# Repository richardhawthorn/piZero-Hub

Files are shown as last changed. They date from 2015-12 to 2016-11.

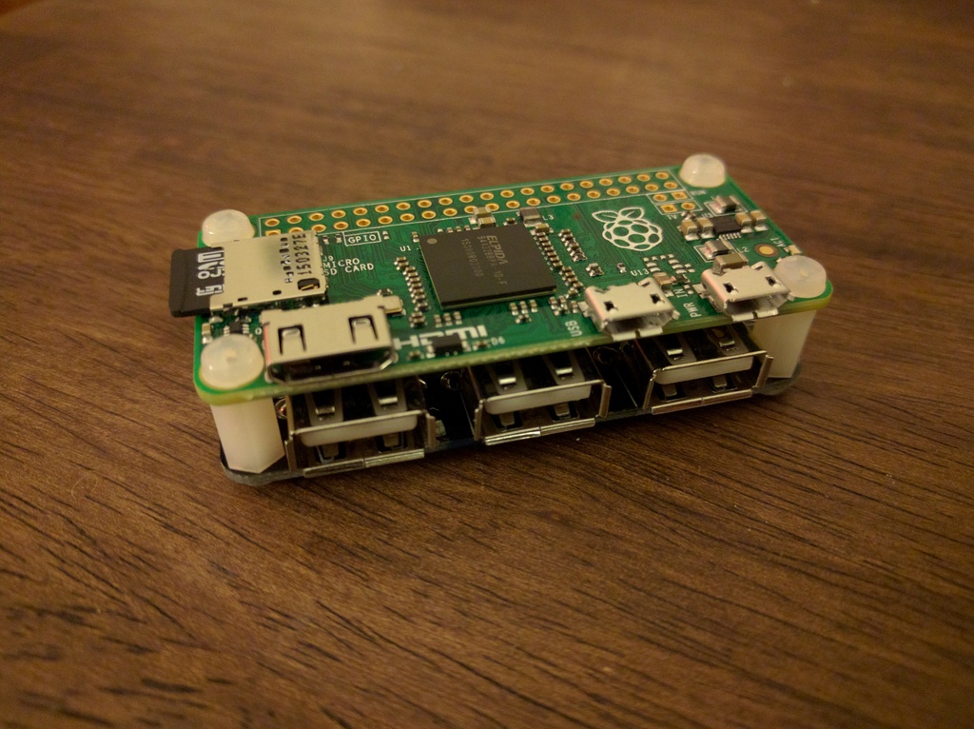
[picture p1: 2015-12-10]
images/image2.jpg

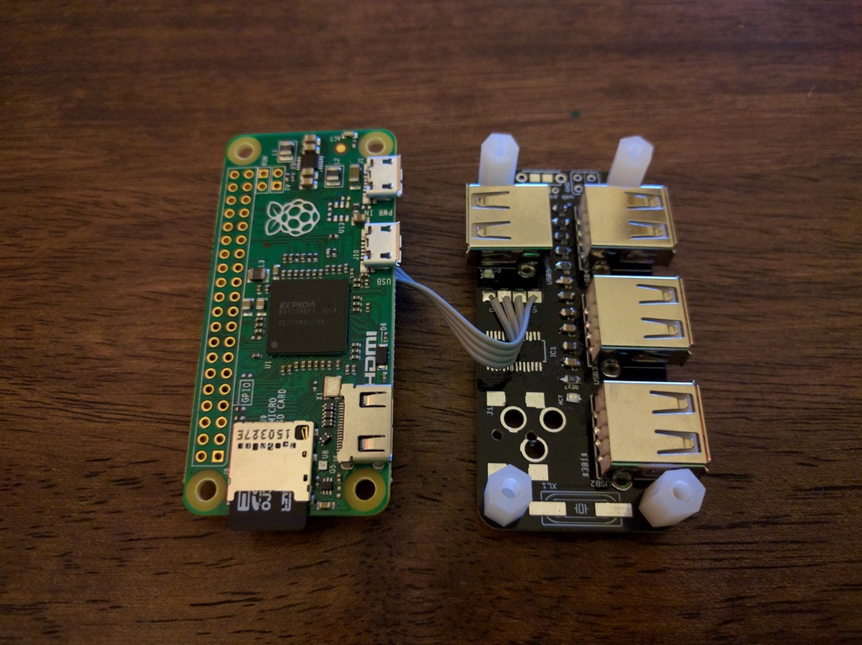
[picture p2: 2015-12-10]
images/image5.jpg

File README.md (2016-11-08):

### Description

USB hub for the Raspberry Pi Zero

### Features

- 4 x USB 2.0 ports
- Micro USB upstream connector
- FE1.1s USB hub chip
- Solder pins for direct connection to the Raspberry Pi Zero
- Power jack connector for external 5v power source
- Optional jumpers to take power from upstream connector
- LED status indicators for each downstream port

### Modes of use

#### 1. Direct solder

You can solder 4 wires directly between the Zero and the hub using 4 pads exposed on both the hub and the Zero. This will connect the 5V, GND, USB D+ and USB D-.

You can then either power the board either using the USB power connector on the Zero, or using the power jack on the hub.

This is the neatest option, although does involve soldering.

#### 2. USB connection

Using a USB OTG cable, or a micro USB to micro USB you can connect the data USB port on the Zero to the upstream USB connector on the side of the hub. Adding the 2 power jumpers allows the hub to use power supplied to the Zero though the power USB connector.

Alternatively, remove the power jumpers and power the hub through the external power jack.

Although a USB cable is needed to connect the two in this mode, no soldering is required.

#### 3. Standalone hub

This board can be used as a regular USB hub, either using power from the upstream USB connector, or through the power jack and external power supply.

### Licence

This work is licensed under the Creative Commons Attribution-ShareAlike 4.0 International License. 
To view a copy of this license, visit http://creativecommons.org/licenses/by-sa/4.0/

Designed by <a xmlns:cc="http://creativecommons.org/ns#" href="http://www.richardhawthorn.com" property="cc:attributionName" rel="cc:attributionURL" target="_blank">Richard Hawthorn</a><br />

Based on design by @MakerBro, https://acrobotic.com

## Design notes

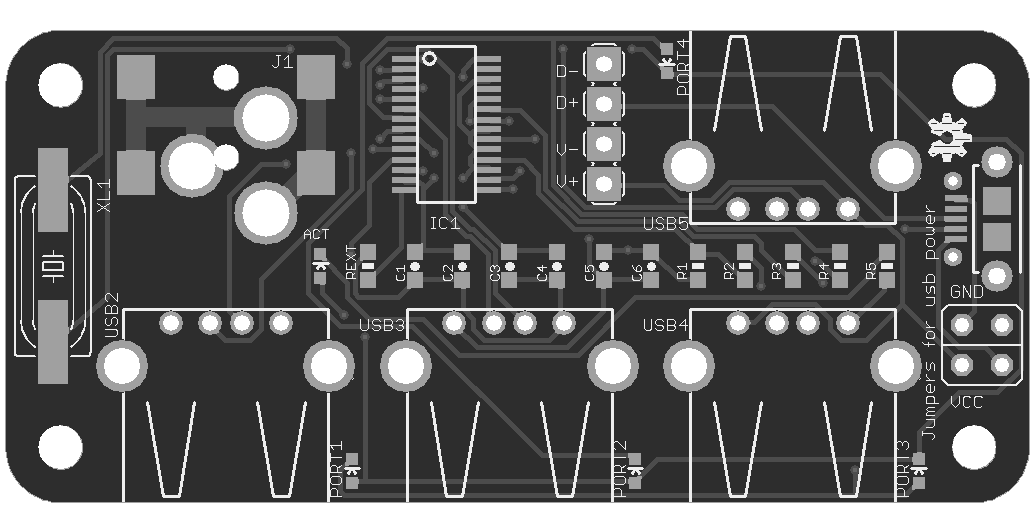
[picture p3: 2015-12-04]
images/pcb_front.png

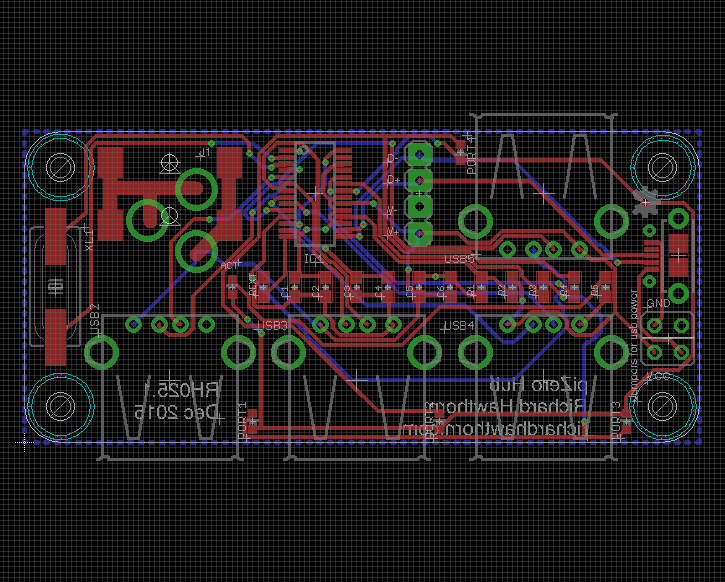
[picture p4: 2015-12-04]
images/eagle.png

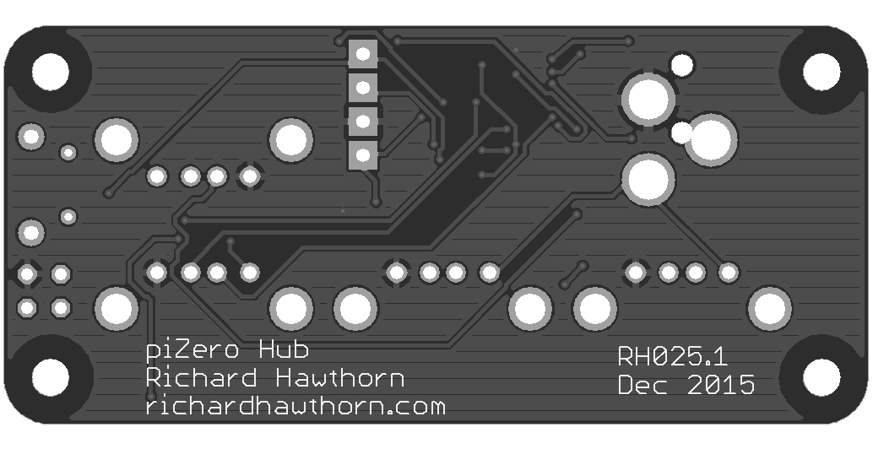
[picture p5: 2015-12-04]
images/pcb_back.png

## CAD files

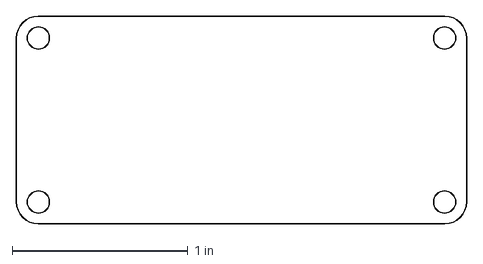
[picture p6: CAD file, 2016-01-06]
enclosure/pizero.dxf
2.56 x 1.18 in

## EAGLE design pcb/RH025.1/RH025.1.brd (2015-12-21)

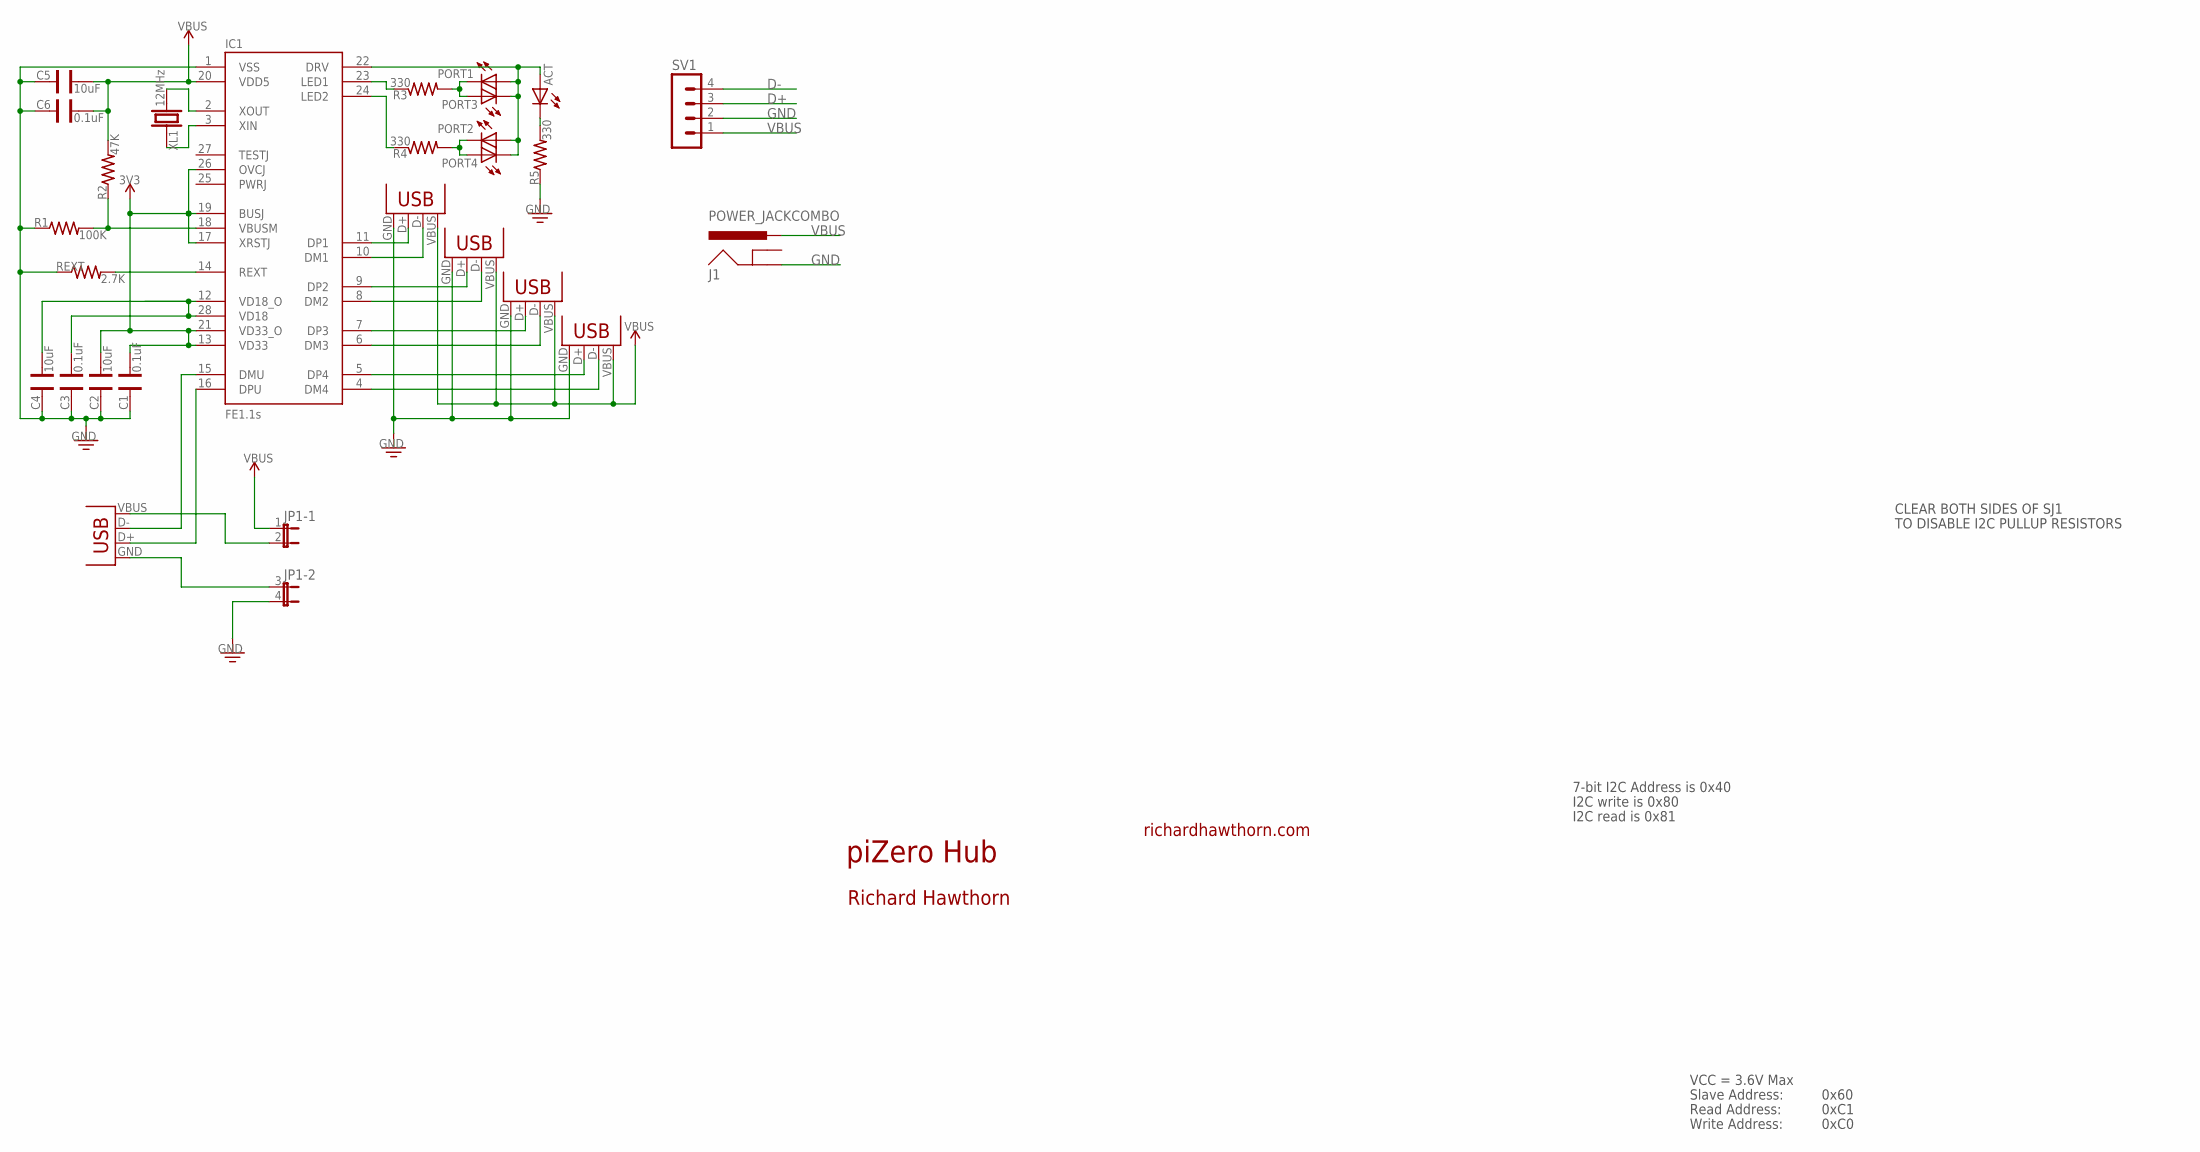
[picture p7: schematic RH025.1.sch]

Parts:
ACT: LED0603; LED-0603
C1, C3, C6: 0.1uF; CAP-0603
C2, C4, C5: 10uF; CAP-0603
IC1: FE1.1S; FE1.1S_SSOP-28
J1: POWER_JACKCOMBO; POWER_JACK_COMBO
JP1: JP2QE; JP2Q
PORT1, PORT2, PORT3, PORT4: LED0603; LED-0603
R1: 100K; RES-0603
R2: 47K; RES-0603
R3, R4, R5: 330; RES-0603
REXT: 2.7K; RES-0603
SV1: MA04-1
USB1: USBMICROB-PTH; USB-MICROB-TH
USB2, USB3, USB4, USB5: USBA-PTH; USB-A-F-PTH
XL1: 12MHz; HC49UP

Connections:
3V3: C1.1, C2.1, IC1.13 (VD33), IC1.17 (XRSTJ), IC1.19 (BUSJ), IC1.21 (VD33_O), IC1.26 (OVCJ)
D+: IC1.16 (DPU), SV1.3, USB1.D+
D-: IC1.15 (DMU), SV1.4, USB1.D-
GND: C1.2, C2.2, C3.2, C4.2, C5.2, C6.2, IC1.1 (VSS), J1.GND@1 (GND), JP1.4 (2), R1.1, R5.1, REXT.1, SV1.2, USB2.GND, USB3.GND, USB4.GND, USB5.GND
unnamed: IC1.14 (REXT), REXT.2
unnamed: JP1.2, USB1.VBUS
unnamed: JP1.3 (1), USB1.GND
unnamed: PORT2.C, PORT4.A, R4.2
unnamed: IC1.2 (XOUT), XL1.2
unnamed: C3.1, C4.1, IC1.12 (VD18_O), IC1.28 (VD18)
unnamed: IC1.3 (XIN), XL1.1
unnamed: IC1.11 (DP1), USB5.D+
unnamed: IC1.10 (DM1), USB5.D-
unnamed: IC1.18 (VBUSM), R1.2, R2.1
unnamed: IC1.9 (DP2), USB4.D+
unnamed: IC1.8 (DM2), USB4.D-
unnamed: IC1.7 (DP3), USB3.D+
unnamed: IC1.6 (DM3), USB3.D-
unnamed: IC1.5 (DP4), USB2.D+
unnamed: IC1.4 (DM4), USB2.D-
unnamed: PORT1.C, PORT3.A, R3.2
unnamed: ACT.C, R5.2
unnamed: IC1.23 (LED1), R3.1
unnamed: IC1.24 (LED2), R4.1
unnamed: ACT.A, IC1.22 (DRV), PORT1.A, PORT2.A, PORT3.C, PORT4.C
VBUS: C5.1, C6.1, IC1.20 (VDD5), J1.POWER (PWR), JP1.1, R2.2, SV1.1, USB2.VBUS, USB3.VBUS, USB4.VBUS, USB5.VBUS

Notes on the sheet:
piZero Hub
richardhawthorn.com
Richard Hawthorn
CLEAR BOTH SIDES OF SJ1
TO DISABLE I2C PULLUP RESISTORS
7-bit I2C Address is 0x40
I2C write is 0x80
I2C read is 0x81
VCC = 3.6V Max
Read Address:
Write Address:
Slave Address:
0x60
0xC1
0xC0

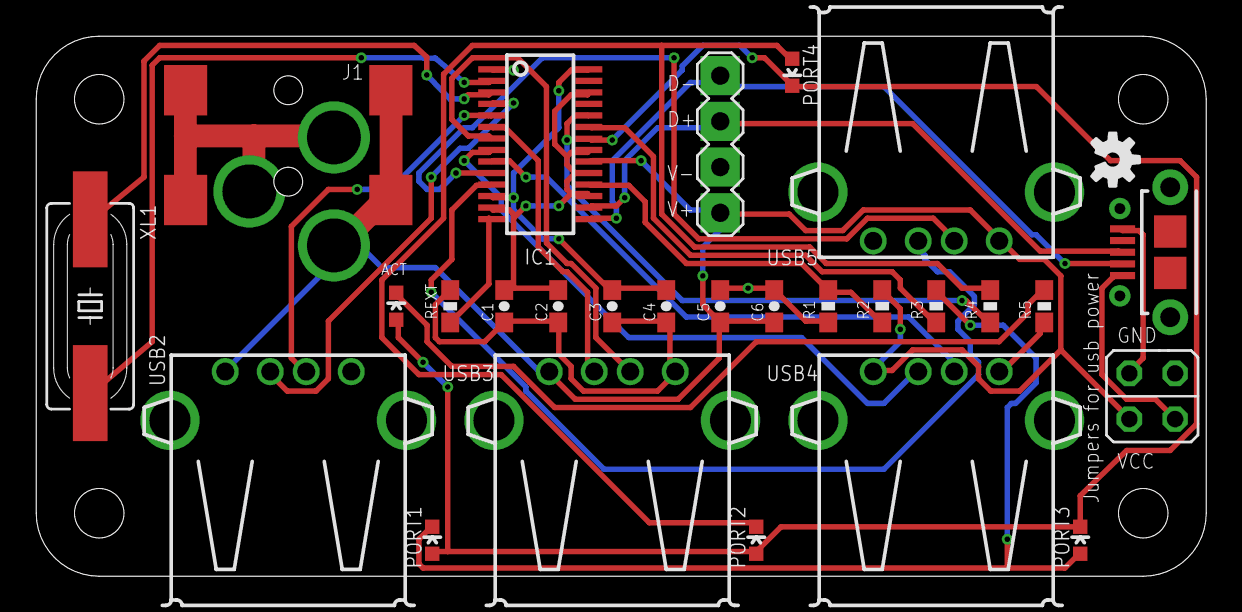
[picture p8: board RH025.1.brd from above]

Board: 2 copper layers, 65.0 x 30.0 mm, 28 parts (0 on the bottom side), 26 nets.

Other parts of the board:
U$3: OSHW-LOGO-S

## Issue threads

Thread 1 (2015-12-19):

Add Eagle files!

kutis96, 2015-12-19:
Eagle files could be particularly nice if someone (like me) would actually go and modify your board.
Hacking it up from images isn't exactly awesome.

Cheers :)

themakerbro, 2015-12-21:
@kutis96 I've been messing around with what seems to be the same IC (FE1.1s) that @richardhawthorn.  I haven't yet fully tested the board, but the design is pretty straight forward from the application note on the data sheet.  EAGLE files here: https://github.com/acrobotic/Ai_Hub_USB

richardhawthorn, 2015-12-21:
Hi @kutis96, I've added the eagle files for you to use, It's actually based on the designs from @themakerbro.

I'm just waiting for the crystal before I can test it.

Cougar, 2015-12-21:
:+1:

themakerbro, 2015-12-21:
:+1:

Love the application for Pi Zeros, Richard. Looking forward to the results of testing!

richardhawthorn, 2016-01-14:
I've received all the components, and the hub works as expected.

ripper121, 2016-01-14:
Is it possible to solder the PCB directly to the Test pads. This will be nice for production.

libboodeploy, 2016-02-18:
@ripper121 You can solder a cable between the two, is that what you mean?

https://github.com/richardhawthorn/piZero-Hub/blob/master/images/image4.jpg

zwave-mke, 2016-02-19:
No i mean you make Holes in your PCB like these for through hole on that positions where the test pins are. Then you lay your PCB direct to the Raspi Zero and put solder on the holes, should look like a Sandwich.

ripper121, 2016-02-19:
No i mean you make Holes in your PCB like these for through hole on that positions where the test pins are. Then you lay your PCB direct to the Raspi Zero and put solder on the holes, should look like a Sandwich.

richardhawthorn, 2016-02-19:
You could certainly re-work the design to line up the holes on the PCB to the pads on the zero.  You could then either solder directly (which might be tricky) or use pogo pins to connect the two.

Pogo pins would be good as you could then disconnect/reconnect easily.

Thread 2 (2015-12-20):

Routing can be fairly improved

kutis96, 2015-12-20:
Here's a couple of minor things that could be improved a bit:
* **Power routing.**
  Those power traces seem a bit too thin to my liking (although they're probably just fine, until something goes wrong)
* **Protection.**
  Maybe add some polyfuses on the power rails of the USB outputs, just if something goes wrong. I know those don't really help much, but eh, better than nothing I suppose. I would also suggest doing something about ESD protection, but I won't bother since that's most likely just fine.
* **Signal routing.**
  Improve the actual signal routing - I can understand that you might have had some trouble making this fit in nicely and all, but it also might be nice to see being USB treated as a differential-signaling bus it actually is. It's actually fairly easy to make Eagle help you route signals differentially - it's just about postfixing the trace labels with either _P or _N as far as I recall. Also, rotating the chip by about 90° anticlockwise would possibly solve a few of those issues? I can't really tell since I couldn't play with it - **release the Eagle files too!**
* **The crystal placement.**
  I know it looks pretty good when it's all placed like this and all, but really... It's often nice when the crystal is just about as close to the chip as possible, and those load capacitors for the crystal should be fairly close to it all. It might not look as pretty, but again - rotating the chip by that 90° might've made that possible.

I hope you appreciate this sort of a feedback/criticism without getting too mad at me or anything, and I'll be quite willing to help if the chance arises :D

Cheers, another Richard.

richardhawthorn, 2015-12-21:
Hey @kutis96, thanks for the notes, I always appreciate feedback.

You're right, I did go for looks in certain places, and the crystal could certainly be closer.  Space was a bit tight too, so it was a tricky balance to make.

I've added the eagle files now too.

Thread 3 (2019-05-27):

Ports are cramped

lukehutch, 2019-05-27:
I'm using the Adafruit Zero4U (I think this GitHub project is what that product is based on?), and need to be able to access multiple USB flash drives at once. Having three USB ports all lined up so close together on one side makes this hub impossible to use with a wide range of USB devices, and I have to use extender cables. Could one of the three side ports be moved to the other side of the board in a future revision, and the remaining two ports spaced out more?

One other physical issue -- the chip below the "Zero4U" logo gets very hot to the touch under load -- I would estimate 75-85 degrees. I am going to have to glue a small heatsink onto the chip. Is there a more recent version that is more power efficient? Or if not, how do I report manufacturing concerns like this to Adafruit? (I am unsure of your relationship to Adafruit.)

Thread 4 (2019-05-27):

Random resets

lukehutch, 2019-05-27:
I have had issues with this board when plugging in multiple USB drives at a time. Sometimes ports will spontaneously stop working (the port light will turn out), and occasionally the entire Raspberry Pi Zero v1.3 will spontaneously reboot.

Is this likely to be a power budget issue, or a Linux kernel driver bug?

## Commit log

2015-12-21 Add PCB files
    [RH025.1.brd, RH025.1.sch]
2016-01-06 added enclosure
    [pizero.dxf]
2016-03-22 added bill of materials

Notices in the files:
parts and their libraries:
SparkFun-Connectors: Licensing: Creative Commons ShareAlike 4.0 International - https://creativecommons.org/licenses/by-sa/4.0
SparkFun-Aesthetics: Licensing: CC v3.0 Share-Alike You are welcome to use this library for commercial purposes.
